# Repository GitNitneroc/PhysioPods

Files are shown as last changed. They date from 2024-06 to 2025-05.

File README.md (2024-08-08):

# Physiopods

## Qu'est-ce que c'est ?
Le but de ce projet est de créer des objets (des pods), utilisés pour jouer, pour la performance sportive ou pour la santé. Différents modes de jeu sont possibles, mais il est par exemple proposé un jeu de réflexes ou il faut appuyer le plus vite possible sur un pod lorsqu'il s'allume. Le score est alors basé sur le délai qu'a mis le joueur, mais aussi sur d'éventuelles erreurs (s'il a appuyé sur un pod éteint).

### Produits similaires
L'idée n'est pas nouvelle. De nombreux produits similaires existent [commercialement](https://www.joueclub.fr/jeux-de-societes/quick-touch-8421134091719.html), ou en projets [open-source](https://github.com/projectswithalex/Reaction-Lights-Training-Module/tree/Version-2).
Nous avons souhaité proposer une alternative avec des objectifs qui nous semblent différents.

### Objectifs du projet
- Nombre de pods : il doit être possible d'utiliser **beaucoup** de pods (la limite actuelle est de 255). Tous les pods sont interchangeables, il n'y a pas de maître ou d'esclave.
- Bon marché : le coût de revient ne doit pas être trop important. Il doit aussi être possible de réparer, de changer des composants ou la batterie.
- Interface web : pour éviter de multiplier les boutons, le gros de l'interface est proposée sur un site web hébergé par les pods. On peut y choisir un mode de jeu, consulter des résultats ou régler des paramètres.
- Polyvalent : les pods doivent pouvoir être posés au sol, fixés avec des sangles ou des ventouses pour permettre des usages différents. De même, le code est prévu pour qu'il soit assez facile d'ajouter d'autres contrôleurs (passer d'un bouton à un capteur capacitif, à un capteur de proximité ou encore à un capteur piezo)

## Utilisation
Le [Wiki](../../wiki) décrit davantage l'utilisation, mais le principe général est qu'il faut allumer un premier pod et attendre quelques secondes. Celui-ci devient le pod principal : on voit d'abord la lumière tourner sur le pod (recherche du wifi), puis faire une petit flash vert : ceci indique que le pod a créé un réseau wifi et attend des connexions. Les autres pods qui s'allumeront se relieront maintenant à celui-ci. Vous pouvez aussi vous connecter au réseau wifi créé. Il s'appelle PhysioPod0, et le mot de passe est "0123456789", en vous connectant, vous serez redirigé vers une page web, c'est là que vous pourrez interragir avec les pods, par exemple pour lancer un mode de jeu ou consulter les résultats.

## Créer ses propres pods
Le processus est décrit dans le [Wiki](../../wiki)

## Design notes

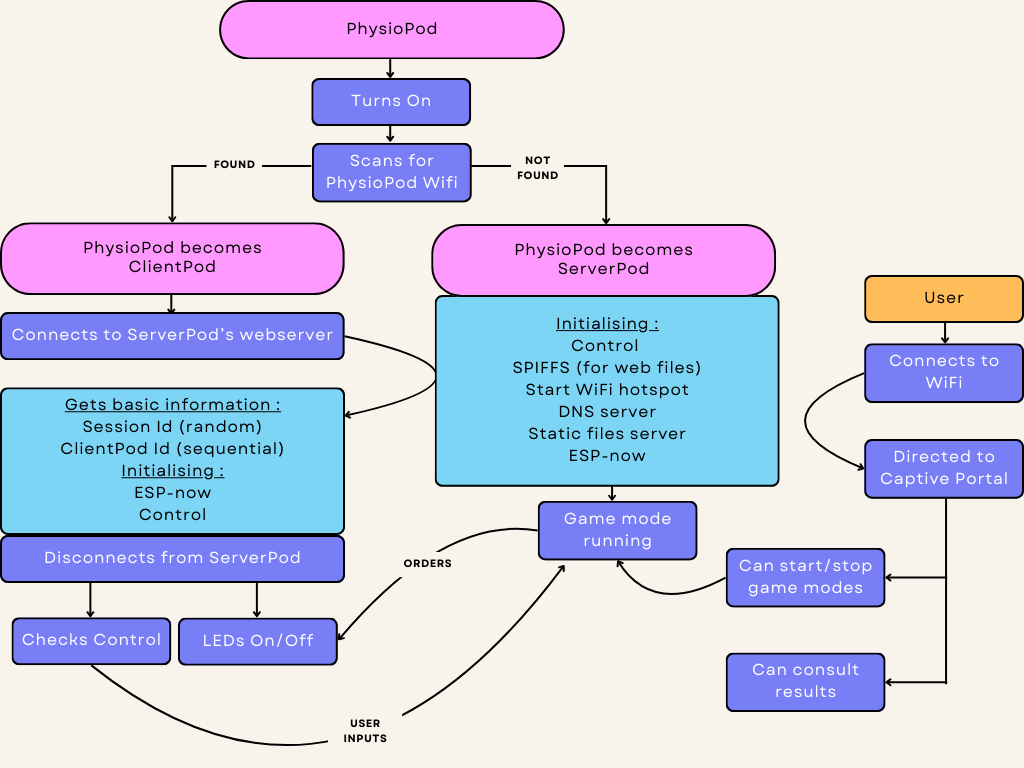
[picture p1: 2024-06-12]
docs/Overview.png

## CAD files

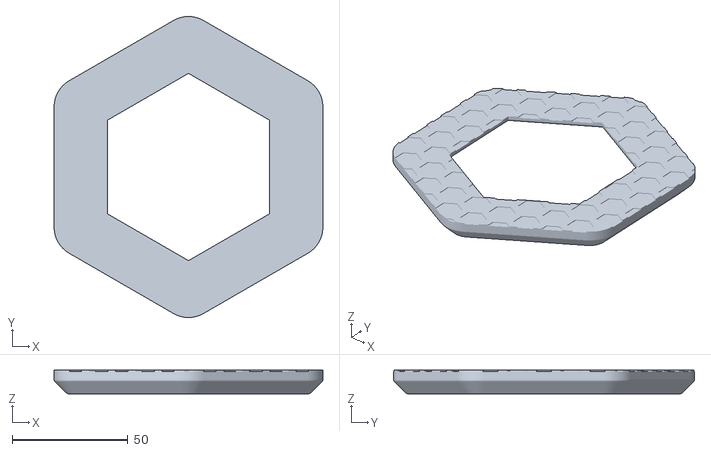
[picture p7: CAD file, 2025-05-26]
Fichiers 3D et STL/Embase TPU PhysioPods v2.stl
116.0 x 129.9 x 10.1

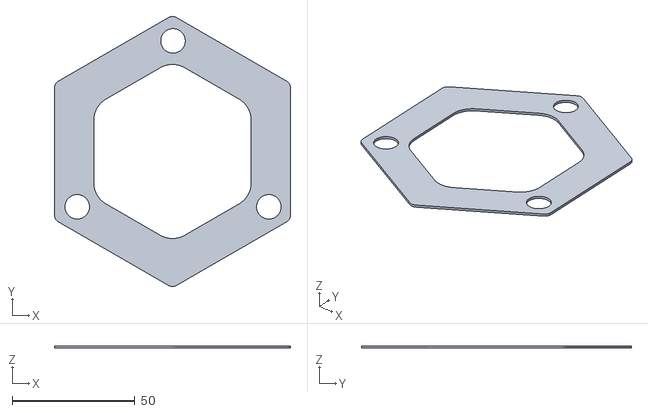
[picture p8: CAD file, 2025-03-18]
Fichiers 3D et STL/STL Base TPU.stl
96.0 x 109.9 x 1.00

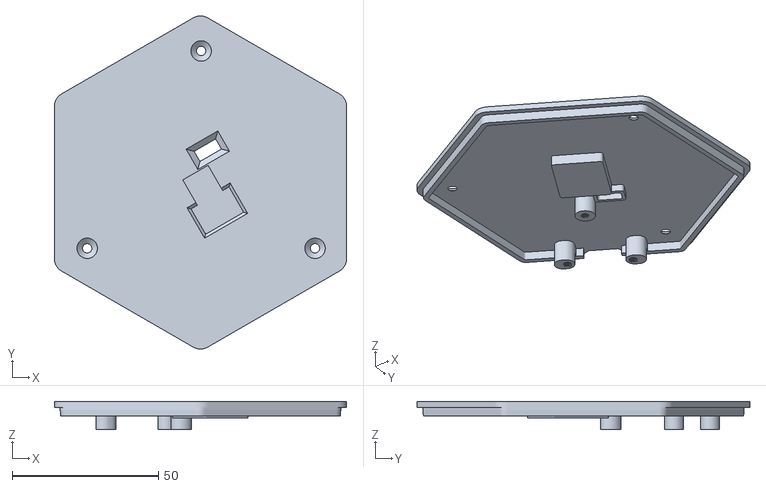
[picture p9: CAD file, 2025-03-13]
Fichiers 3D et STL/STL Base AVEC Espalier.stl
100.0 x 113.9 x 9.60

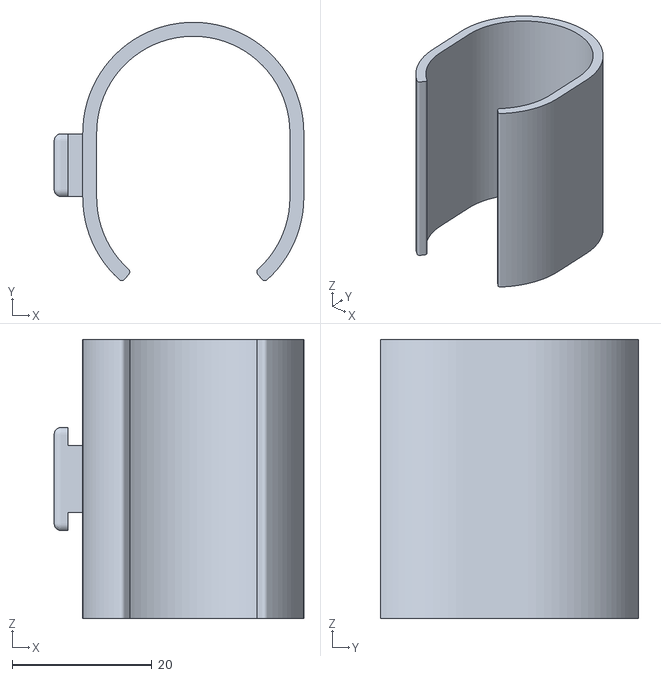
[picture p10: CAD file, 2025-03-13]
Fichiers 3D et STL/STL Attache Espalier.stl
35.8 x 37.0 x 40.0

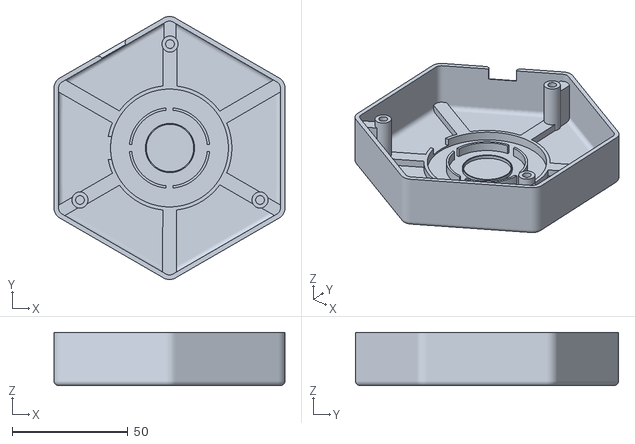
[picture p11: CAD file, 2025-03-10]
Fichiers 3D et STL/STL Boitier Inserts v57.stl
100.0 x 113.9 x 23.0

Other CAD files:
Fichiers 3D et STL/STL Base sans Espalier v57.stl
Fichiers 3D et STL/STL Boitier Vis v57.stl

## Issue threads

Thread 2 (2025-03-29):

Timer HIIT

GitNitneroc, 2025-03-29:
- Réglages sur l'appli:

 - - Sur le principe d'un timer HIIT, pouvoir régler le temps d'effort et de repos
 - - Au choix
 - - - Durée totale d'une session
 - - - Régler un nombre de cucles donné (si par exemple on présente 6 exercices au patient, entrer 6 et ça programme tout seul 6x(Effort+Repos)

- Affichage : l'"anneau de LEd affichera l'avancée dans le temps d'effort en rouge, le temps de repos en bleu ou vert. Si possible au début du temps toutes les LEds sont allupées à 50% et avec l'avancée l'anneau colore les Leds à 100% une par une. SI par exemple 20sec est défini, à 5 sec, les 3 premières Leds sont à 100% le reste à 50%, à 15sec 9 LEds seront à 100% et les 3 restantes à 50% si possible de jour sur l'intensité, jouer sur la coloration plus ou moins claire
- Standalone : à l'avenir l'idéal serait que ce mode puisse se lancer en "standalone" à l'aide de boutons physiques.

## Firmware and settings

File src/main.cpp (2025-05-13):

#include "ServerPod.h"
#include "ClientPod.h"
#include "debugPrint.h"


PhysioPod* pod = nullptr;
bool shouldBeClient = false;

//TODO : physioPodMode aller/retour...
//TODO : dans le mode ChasePod, un timer,qui dit en combien de temps on fait un cycle
//TODO : dans fastPress donner les résultats selon la durée/nombre de pressions
//TODO : on peut obtenir l'adresse mac du serveur simplement avec WiFi.BSSID()
//TODO : afficher des stats plus sexy dans les résultats

void createPod();

void setup(){
    Serial.begin(115200);
    /* #ifdef isDebug
    //This was just a stupid delay to facilitate debugging of the first steps. It's not needed right now but could be useful in the future
    //delay for the serial monitor to start
    vTaskDelay(3000 / portTICK_PERIOD_MS);
    #endif */
    
    #ifdef isDebug
    DebugPrint("Booting, version ");
    DebugPrintln(VERSION);
    DebugPrintln("compiled " __DATE__ " " __TIME__ );
    DebugPrint("Executing on core ");
    DebugPrintln(xPortGetCoreID());
    #endif

    PhysioPod::initLEDs(); //initialize the LEDs, this cannot be done in createPod because we don't know if we are a server or a client yet
    //some color correction can be done here if needed on your setup (include FastLED.h to use this) :
    //FastLED.setCorrection(TypicalLEDStrip);
    //FastLED.setTemperature( Tungsten100W );
    //FastLED.setBrightness(200); //uint8_t value for scale

    //WiFi.persistent(false); //we have to use the default persistent mode, because we use esp_wifi.h functions

    shouldBeClient = PhysioPod::searchOtherPhysioWiFi();//this is a blocking call
    if (shouldBeClient){
        DebugPrintln("Server found ! Starting as a client...");
    }else{
        DebugPrintln("No server found ! Starting as a server...");
    }

    DebugPrintln("Creating the pod...");
    createPod(); //pod should not be nullptr anymore
}

void createPod(){
    if (shouldBeClient){
        pod = new ClientPod();
    }else{
        ScoreStorage::init();
        ServerPod* serverPod = new ServerPod();
        pod = serverPod;
    }
    //make the pod blink once, to show that it is ready, and to be sure that LED(s) are working and off when we start
    pod->setOwnLightState(true, (shouldBeClient? CRGB::Blue : CRGB::Green) , LightMode::PULSE_ON_OFF_LONG); //Note : Pulse reverts to off state after the pulse
}

void loop(){
    //for battery maybe we could add a small delay, especially if we are a client ?
    pod->updatePod();
}

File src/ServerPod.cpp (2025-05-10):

#include "ServerPod.h"

//The libraries we need
#include <DNSServer.h>
#ifdef ESP32
#include <WiFi.h>
#include <AsyncTCP.h>
#elif defined(ESP8266)
#include <ESP8266WiFi.h>
#include <ESPAsyncTCP.h>
#endif
#include "ESPAsyncWebServer.h"
#include <esp_now.h>
#include <esp_wifi.h>

#include "SPIFFS.h"
//OTA
//#include <ElegantOTA.h>
#include <PrettyOTA.h>

#include "debugPrint.h"

//Our handlers for the web server
#include "handlers/LEDRequestHandler.h"
#include "handlers/CaptiveRequestHandler.h"
#include "handlers/ServerRegistrationHandler.h"
#include "handlers/ModeLaunchHandler.h"
#include "handlers/ScoreJSONHandler.h"
#include "handlers/ModeInfoHandler.h"
#include "handlers/ModeStopHandler.h"
#include "handlers/PeersNumHandler.h"
#include "handlers/SSIDHandler.h"

#include "modes/PhysioPodMode.h"

#include "Messages.h"
using namespace Messages;

#define MAX_CLIENTS 4 //The maximum number of clients that can connect to the server
#define LOCAL_IP "http://192.168.1.1"
#define LOCAL_URL "/static/index.html"
#define LOCAL_OTA_URL "/update" //The URL for the OTA update
#define LOCAL_IP_URL LOCAL_IP LOCAL_URL 
#define LOCAL_OTA_IP_URL LOCAL_IP LOCAL_OTA_URL

#define LIMIT_AP_START_ATTEMPTS 100 //The number of attempts a serverpod makes to start the AP before restarting

//ServerPod* ServerPod::instance = nullptr;
const uint8_t ServerPod::ip_addr_broadcast[6] = {0xff, 0xff, 0xff, 0xff, 0xff, 0xff};
uint8_t ServerPod::peersNum = 0;

PrettyOTA OTAUpdates;

void ServerPod::OnAPStart(WiFiEvent_t event, WiFiEventInfo_t info){
    //This is used to make sure the AP is started before we continue
    ServerPod::getInstance()->APStarted = true;
}

bool ServerPod::initializeSPIFFS(){
    //start the SPIFFS
    if(!SPIFFS.begin(true)){
        DebugPrintln("An Error has occurred while mounting SPIFFS filesystem");
        return false;        
    }
    //test a file
    if (!SPIFFS.exists("/www/index.html")) {
        DebugPrintln("index.html was not found, you probably forgot to upload the files to SPIFFS");
        return false;
    }
    staticFilesEnabled = true; //set the static files to be served    
    #ifdef isDebug
    DebugPrintln("|-SPIFFS mounted successfully");
    #endif
    return true;
}

void ServerPod::prepareCaptivePortal(AsyncWebServer* server, bool sendToOTA){
    //captive portal for the server from https://github.com/CDFER/Captive-Portal-ESP32/tree/main
    // Required
    server->on("/connecttest.txt", [](AsyncWebServerRequest *request) { request->redirect("http://logout.net"); });	// windows 11 captive portal workaround
    server->on("/wpad.dat", [](AsyncWebServerRequest *request) { request->send(404); });								// Honestly don't understand what this is but a 404 stops win 10 keep calling this repeatedly and panicking the esp32 :)

    const char* redirection = sendToOTA ? LOCAL_OTA_IP_URL : LOCAL_IP_URL;

    // Background responses: Probably not all are Required, but some are. Others might speed things up?
    // A Tier (commonly used by modern systems)
    server->on("/generate_204", [redirection](AsyncWebServerRequest *request) { request->redirect(redirection); });		   // android captive portal redirect
    server->on("/redirect", [redirection](AsyncWebServerRequest *request) { request->redirect(redirection); });			   // microsoft redirect
    server->on("/hotspot-detect.html", [redirection](AsyncWebServerRequest *request) { request->redirect(redirection); });  // apple call home
    server->on("/library/test/success.html", [redirection](AsyncWebServerRequest *request) { request->redirect(redirection); });		   // legacy apple call home
    server->on("/canonical.html", [redirection](AsyncWebServerRequest *request) { request->redirect(redirection); });	   // firefox captive portal call home
    server->on("/success.txt", [](AsyncWebServerRequest *request) { request->send(200); });					   // firefox captive portal call home
    server->on("/ncsi.txt", [redirection](AsyncWebServerRequest *request) { request->redirect(redirection); });			   // windows call home

    server->on("/generate204", [redirection](AsyncWebServerRequest *request) { request->redirect(redirection); });

    // B Tier (uncommon)
    //  server.on("/chrome-variations/seed",[](AsyncWebServerRequest *request){request->send(200);}); //chrome captive portal call home
    //  server.on("/service/update2/json",[](AsyncWebServerRequest *request){request->send(200);}); //firefox?
    //  server.on("/chat",[](AsyncWebServerRequest *request){request->send(404);}); //No stop asking Whatsapp, there is no internet connection
    //  server.on("/startpage",[](AsyncWebServerRequest *request){request->redirect(LOCAL_IP_URL);});
}

void ServerPod::attachHandlers(AsyncWebServer* server){
    DebugPrintln("|-Adding the web handlers to the server...");
    //handlers for the web server
    server->addHandler(new ModeInfoHandler()); //Handles the requests for informations about the current mode
    server->addHandler(new PeersNumHandler()); //Handles the requests for the number of connected peers
    server->addHandler(new ModeStopHandler()); //Handles the mode stop request
    server->addHandler(new ModeLaunchHandler()); //Handles the mode launch request
    server->addHandler(new ServerRegistrationHandler()); //Handles the server mac address request
    server->addHandler(new LEDRequestHandler()); //Handles the LED control requests
    server->addHandler(new ScoreJSONHandler()); //Handles the score requests
    server->addHandler(new SSIDHandler()); //Handles the ssid change request
}

//this is a callback when the OTA update starts
//used to unmount the SPIFFS filesystem if the OTA update is going to update the filesystem
void onOTAUpdateStart(NSPrettyOTA::UPDATE_MODE updateMode)
{
    // Is the filesystem going to be updated?
    if(updateMode == NSPrettyOTA::UPDATE_MODE::FILESYSTEM)
    {
        // Unmount SPIFFS filesystem here
        SPIFFS.end();
    }
}
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

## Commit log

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2024-02-13 Début d'un mode de "jeu" basique où il faut appuyer vite quand la LED s'allume
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2024-02-17 Le mode se lance maintenant via la page dédiée, avec des paramètres modifiables par l'utilisateur
2024-02-17 Un peu de CSS pour faire plus joli, même si ça n'est pas très réussi
2024-02-18 Création d'une page de résultats. Un nouveau handler regroupe tous les html statiques.
2024-02-19 First memory leak identified and fixed
    [main.cpp]
2024-02-23 Stockage des scores, qui sont aussi affichés, le mode Fastpress a maintenant un paramètre pour le nombre d'essais
2024-02-23 Création de pins.h pour partager les defs de pins
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2024-02-25 Ajout d'un messages.h pour les données envoyées via espnow
2024-02-25 Le serveurpod broadcaste les messages de LED. Le clientpod ne les lit pas encore
2024-02-25 On ne renvoit plus toute la page quand on a juste allumé/éteint une LED
2024-02-25 correction des chemins relatifs dans les includes
    [LEDRequestHander.cpp]
2024-02-27 Les messages sont maintenant broadcastés depuis le serveur. Il n'y a plus que 1 pair : broadcast sur le serveur et serveur sur le client. TODO : attribuer des ids corrects maintenant
    [LEDRequestHander.cpp, ServerMacAddressHandler.cpp, main.cpp]
2024-02-28 Les clientPods reçoivent leur id, le serveur sait écrire au bon, on peut donc les contrôler indépendemment
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2024-03-03 Meilleur support des S3/C3 avec des build flags
2024-03-03 Corrections sur les LED inversés du C3
    [LEDRequestHander.cpp, main.cpp]
2024-03-03 restarting if error adding broadcast as peer on serverPod
    [main.cpp]
2024-03-05 Gros refactoring du code, Avec des classes ClientPod et ServerPod. ScoreStorage est maintenant un espace de noms
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2024-03-06 LED_PIN est maintenant un build-flag plutôt qu'un define
2024-03-07 Les scores remarchent. Attention quand on lance un mode sans que le précédent soit terminé
2024-03-07 Les scores sont maintenant bien gérés... ATTENTION les modes ne sont jamais détruits, il y a donc une fuite de mémoire à corriger, mais il faudrait réfléchir à comment les détruire au mieux
    [ServerPod.cpp]
2024-03-07 Le mode FastPress comprend maintenant combien de pods sont connectés
2024-03-08 C'est maintenant le main qui ajoute les handlers, et plus le serverPod lui-même
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2024-03-09 amélioration de l'interface web, début de la possibilité de relancer le mode précédent. NB : toujours pas de delete sur un mode remplacé !
2024-03-09 Le bouton pour relancer fonctionne... Mais il y a une erreur sur le score à nouveau... Quand un mode s'arrête ? Quand il est interrompu ? En tout cas le score peut être écrasé par un vide
2024-03-10 Meilleure orga entre PhysioPodMode et ses dérivées. Attention, quand FastPressMode se termine, il efface son propre score !
2024-03-10 Correction pour le score, mais le setup est trop long je pense
    [main.cpp]
2024-03-10 LED qui clignote en cherchant le WIFI... Ca serait mieux plus lentement, sans delay, et d'une couleur plus cool, donc une couleur en paramètre ?
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2024-03-12 On peut maintenant aussi utiliser un capteur capacitif plutôt que le bouton
2024-03-13 Un mode guirlande en plus, qui pourra servir de démo car c'est un mode hyper simple
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2024-03-14 Correction d'un crash stupide
    [ServerPod.cpp]
2024-03-14 Meilleur delete du mode remplacé par un nouveau, suite à un crash étrange... Mais en voilà un autre, il faut se demander si je n'ai pas introduit un truc bizarre quand même
    [ServerPod.cpp]
2024-03-17 Renommage de serverMacAddress en serverRegistration, et ajout d'une version qui s'assure de la compatibilité
2024-03-17 Préparations pour qu'on ait un sessionId, qu'il va maintenant falloir ajouter à tous les messages
2024-03-17 Premiers échanges de session Ids dans les messages, mais il faut encore vérifier qu'ils sont respectés
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2024-03-19 On peut maintenant demander à un pod de s'allumer d'une couleur précise
2024-03-26 Correct the buttonControl problem on S3
    [main.cpp]
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2024-03-26 Meilleure gestion des scores, mais toujours un plantage si on relance un colorWarMode vite...
2024-03-26 correction des erreurs au build pour C3
2024-03-26 La LED du C3 marche maintenant correctement
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2024-04-06 Corrections Couleurs Leds et affichage résultats
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2024-04-06 On a maintenant les couleurs des équipes dans le ColorWar quand on choisir le nombre d'équipes
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2024-04-13 Le statut du mode est maj quand on relance/arrête depuis la page principale
2024-04-13 Les css n'était pas toujours bien référencé et redirection ajoutée sur les lancements de modes
2024-04-13 MAJ de LEDRequestHandler, dont le nom de fichier était faux, et qui datait un peu
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2024-04-22 Correction Erreur nom de fichier
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2024-04-26 Timeout chez les clients aussi : ils redémarrent si le serveur est introuvable. On rajoute un délai pour ceux qui ont un id >1.
2024-04-30 Plutôt que de scanner les réseaux, on tente une connection, ça semble bcp plus rapide
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2024-05-14 Correction petit bug dans le modeChoice de ColorWar
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2024-05-15 Some led color/brightness corrections examples are included
    [main.cpp]
2024-05-20 les clients lisent maintenant le mode de LED qui leur a été adressé
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2024-05-26 Le mode fairy lights n'enregistrait pas de score quand il s'arrêtait... C'est pas très utile mais c'est plus logique comme ça
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2024-05-28 Support des Pulses, bien pratique pour ne pas avoir à remettre off après
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2024-06-05 Le seuil du capacitif devient une variable d'environement, et les PULSE sont affichés comme modes de lumière dans l'accueil
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2024-06-23 Bug dans les les modes d'allumages corrigé
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2024-06-23 Correction fuite de mémoire, le bug reste présent
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2024-06-25 debug msg in case the bug comes from multi-core platforms
    [main.cpp]
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2024-07-21 Add files via upload
    Fichiers pour impression 3D et Gerber pour commande de PCB
    [BOM_PhysioPods-V3_2024-07-21.csv, Boitier Inserts STL.stl, Boitier Vis STL.stl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]
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2024-07-24 ajout d'un fichier pour rings 16 leds
    [PhysioPods 16Bit Ring v3.stl]
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2024-07-24 Correction de guillemets
2024-07-27 Button_pin replaced by control_pin for clarity
    [main.cpp]
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2024-08-14 Add files via upload
    Renfort des fixations au couvercle et changement de la fixation Piezo
    [Boitier Inserts V50.stl, Boitier Vis V50.stl]
2024-08-14 Add files via upload
    Renfort des fixations au couvercle et changement fixation Piezo
    [Boitier Ring 16bit V50.stl]
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2024-12-01 modifs du fastPress liés au passage au 10ème de seconde des params du fastPress
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2025-03-10 Mise à jour des fichiers
    Gros rafraichissement des versions STL et Fusion
    [STL Base Espalier v57.stl, STL Base sans Espalier v57.stl, STL Boitier Inserts v57.stl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]
2025-03-13 Add files via upload
    Attache centrée avec plafond de l'encoche.
    [Attache Espalier.stl, STL Base AVEC Espalier.stl]
2025-03-13 Rename Attache Espalier.stl to STL Attache Espalier.stl
    [STL Attache Espalier.stl]
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2025-03-15 Plusieurs couleurs au mode FastPress... Attention les pièges ne doivent probablement plus fonctionner
2025-03-18 Base TPU pour version avec encoche espalier
    [STL Base TPU.stl]
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2025-04-06 refactor: fix button group solid button border width
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2025-04-14 HIIT timer is now displayed on all pods instead of juste server
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2025-04-30 Initial tests to turn the piezzo into a buzzer
    [main.cpp]
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2025-05-10 Basis for buzzer usage
    [ServerPod.cpp]
2025-05-13 Correction du bug sur les LEDS des modes d'affichage Loading et unloading
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2025-05-26 Nouvelle embase en TPU de stabilisation au sol
    [Embase TPU PhysioPods v2.stl]
